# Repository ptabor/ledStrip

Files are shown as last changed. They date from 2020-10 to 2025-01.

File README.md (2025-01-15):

# ledStrip
Hobby project of (3-channel) addressable led-strips controller PCB and arduino code.

Features: 
  - power rating: 12V x 15A = 180 W combined (as designed, but depends on actual components you will use)
  - 3 channels (12V), each rated at 7A, having it's own fuse, 5V logic - tested on:
     - [WS2812B](https://www.amazon.com/stores/BTF-LIGHTING/page/0FF60378-45DE-44E7-B0D7-8F5CD6478971?ref_=ast_bln) strips.
     - [WS2815](https://www.amazon.com/stores/page/DC3DD961-F922-4197-AFD3-9C96122A1429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)
     - (but should work with any 12V power, 5V logic strips)
  - ESP32 (devkit C) powered, with Wifi support  - Web-Server control and remote firmware update 
  - [MSGEQ7](https://www.digikey.lu/htmldatasheets/production/2071107/0/0/1/MSGEQ7.pdf) spectrum analyzer connected to 3.5mm Audio Jack.
  - USB-A port (0.8A) to power the remote audio-player. 

## PCB

### Front

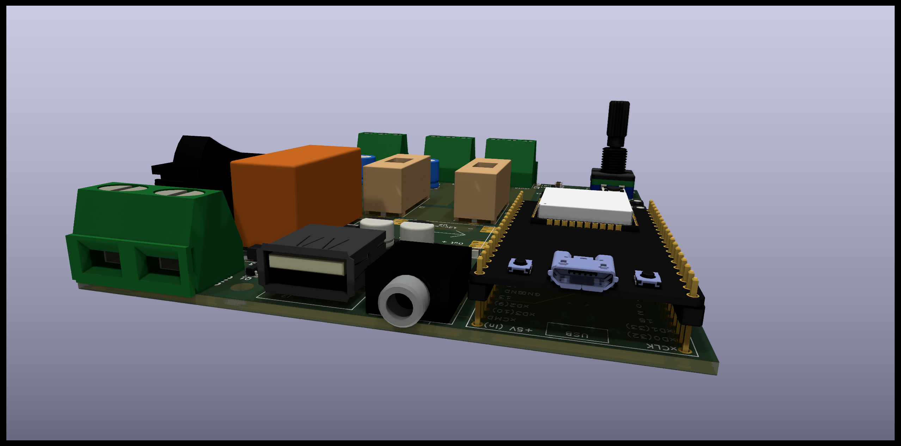
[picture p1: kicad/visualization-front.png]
Front view

  
### Back

Back view

## Building with Arduino IDE:

Install in Arduine IDE board manager:
 -ESP32
 -ESP32 from expressif 

In Arduino IDE Library manager:
 - ESP32Encoder 0.10.2
  
## WARNING

THE SOFTWARE AND HARDWARE DESIGN IS PROVIDED “AS IS”, WITHOUT WARRANTY OF ANY KIND, EXPRESS OR IMPLIED, 
INCLUDING BUT NOT LIMITED TO THE WARRANTIES OF MERCHANTABILITY, 
FITNESS FOR A PARTICULAR PURPOSE AND NONINFRINGEMENT. 
IN NO EVENT SHALL THE AUTHORS OR COPYRIGHT HOLDERS BE LIABLE FOR ANY CLAIM, 
DAMAGES OR OTHER LIABILITY, WHETHER IN AN ACTION OF CONTRACT, TORT OR OTHERWISE, 
ARISING FROM, OUT OF OR IN CONNECTION WITH THE SOFTWARE OR THE USE OR OTHER DEALINGS IN THE SOFTWARE.

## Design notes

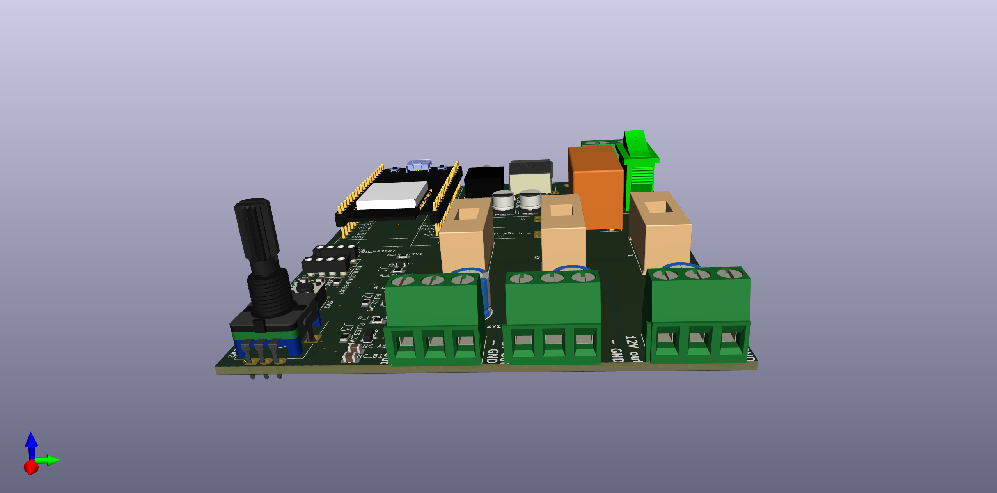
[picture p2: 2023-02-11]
kicad/visualization-back.png

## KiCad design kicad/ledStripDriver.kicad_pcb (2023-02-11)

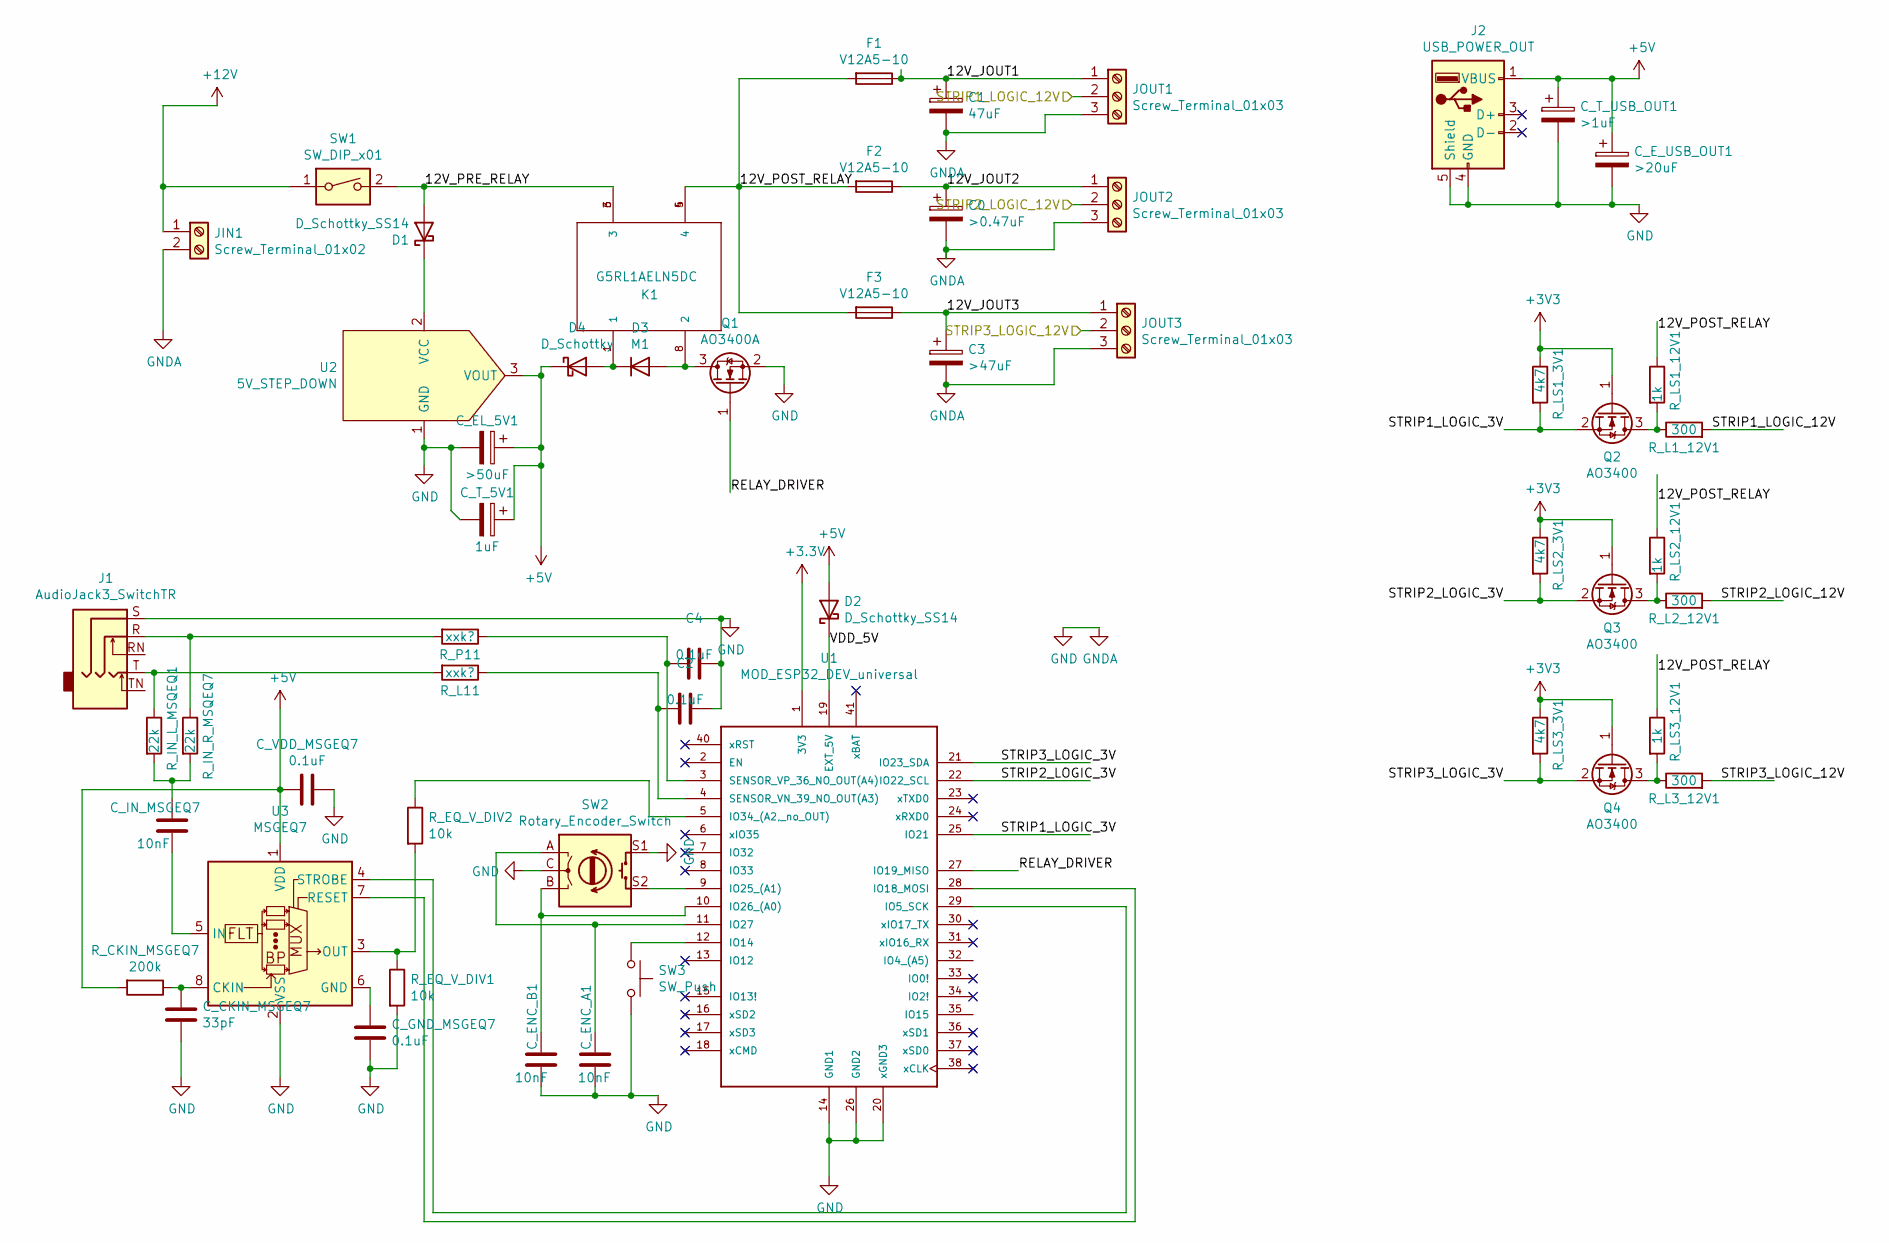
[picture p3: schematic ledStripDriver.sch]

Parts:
C0: >0.47uF; CP_Radial_D8.0mm_P3.80mm
C1: 47uF; CP_Radial_D8.0mm_P3.80mm
C2, C4: 0.1uF; C_0805_2012Metric_Pad1.15x1.40mm_HandSolder
C3: >47uF; CP_Radial_D8.0mm_P3.80mm
C_CKIN_MSGEQ7: 33pF; C_0805_2012Metric_Pad1.15x1.40mm_HandSolder
C_EL_5V1: >50uF; CP_Elec_6.3x5.4
C_ENC_A1: 10nF; C_0805_2012Metric_Pad1.15x1.40mm_HandSolder
C_ENC_B1: 10nF; C_0805_2012Metric_Pad1.15x1.40mm_HandSolder
C_E_USB_OUT1: >20uF; CP_Elec_6.3x5.4
C_GND_MSGEQ7: 0.1uF; C_0805_2012Metric_Pad1.15x1.40mm_HandSolder
C_IN_MSGEQ7: 10nF; C_0805_2012Metric_Pad1.15x1.40mm_HandSolder
C_T_5V1: 1uF; C_0805_2012Metric_Pad1.15x1.40mm_HandSolder
C_T_USB_OUT1: >1uF; C_0805_2012Metric_Pad1.15x1.40mm_HandSolder
C_VDD_MSGEQ7: 0.1uF; C_0805_2012Metric_Pad1.15x1.40mm_HandSolder
D1, D2: D_Schottky_SS14; D_SMA_Handsoldering
D3: M1; D_SMA_Handsoldering
D4: D_Schottky; D_SMA_Handsoldering
F1, F2, F3: V12A5-10; Fuseholder_Cylinder-5x20mm_Stelvio-Kontek_PTF78_Horizontal_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
J1: AudioJack3_SwitchTR; AudioJack3_SwitchTR_PJ3024
J2: USB_POWER_OUT; USB_A_CONNFLY_DS1095-WNR0
JIN1: Screw_Terminal_01x02; TerminalBlock_RND_205-00023_1x02_P10.00mm_Horizontal(2mmdri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
JOUT1, JOUT2, JOUT3: Screw_Terminal_01x03; TerminalBlock_RND_205-00002_1x03_P5.00mm_Horizontal
K1: G5RL1AELN5DC; RELAY_G5RL1AELN12DC
Q1: AO3400A; SOT-23
Q2, Q3, Q4: AO3400; SOT-23
R_CKIN_MSGEQ7: 200k; R_0805_2012Metric_Pad1.15x1.40mm_HandSolder
R_EQ_V_DIV1, R_EQ_V_DIV2: 10k; R_0805_2012Metric_Pad1.15x1.40mm_HandSolder
R_IN_L_MSQEQ1: 22k; R_0805_2012Metric_Pad1.15x1.40mm_HandSolder
R_IN_R_MSQEQ7: 22k; R_0805_2012Metric_Pad1.15x1.40mm_HandSolder
R_L1_12V1, R_L2_12V1, R_L3_12V1: 300; R_0805_2012Metric_Pad1.15x1.40mm_HandSolder
R_L11: xxk?; R_0805_2012Metric_Pad1.15x1.40mm_HandSolder
R_LS1_3V1, R_LS2_3V1, R_LS3_3V1: 4k7; R_0805_2012Metric_Pad1.15x1.40mm_HandSolder
R_LS1_12V1, R_LS2_12V1, R_LS3_12V1: 1k; R_0805_2012Metric_Pad1.15x1.40mm_HandSolder
R_P11: xxk?; R_0805_2012Metric_Pad1.15x1.40mm_HandSolder
SW1: SW_DIP_x01; ROCKER_SWITCH_7x0.5mm
SW2: Rotary_Encoder_Switch; RotaryEncoder_Alps_EC12E-Switch_Vertical_H20mm
SW3: SW_Push; SW_PUSH_6mm
U1: MOD_ESP32_DEV_universal; MOD_ESP32_DEV_DEVKITC-32D
U2: 5V_STEP_DOWN; DC_STEP_DOWN_MODULE_223_17
U3: MSGEQ7; DIP-8_W7.62mm_Socket

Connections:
+5V: C_EL_5V1.1, C_E_USB_OUT1.1, C_T_5V1.1, C_T_USB_OUT1.1, C_VDD_MSGEQ7.2, D2.2 (A), D4.1 (K), J2.1 (VBUS), R_CKIN_MSGEQ7.2, U2.3 (VOUT), U3.1 (VDD)
+12V: JIN1.1, SW1.1
/12V_JOUT1: C1.1, F1.1, JOUT1.1
/12V_JOUT2: C0.1, F2.1, JOUT2.1
/12V_JOUT3: C3.1, F3.1, JOUT3.1
/12V_POST_RELAY: F1.2, F2.2, F3.2, K1.4, K1.5 (4), R_LS1_12V1.1, R_LS2_12V1.1, R_LS3_12V1.1
/12V_PRE_RELAY: D1.2 (A), K1.3, K1.6 (3), SW1.2
/RELAY_DRIVER: Q1.1 (G), U1.27 (IO19_MISO)
/STRIP1_LOGIC_3V: Q2.2 (S), R_LS1_3V1.2, U1.25 (IO21)
/STRIP1_LOGIC_12V: JOUT1.2, R_L1_12V1.2
/STRIP2_LOGIC_3V: Q3.2 (S), R_LS2_3V1.2, U1.22 (IO22_SCL)
/STRIP2_LOGIC_12V: JOUT2.2, R_L2_12V1.2
/STRIP3_LOGIC_3V: Q4.2 (S), R_LS3_3V1.2, U1.21 (IO23_SDA)
/STRIP3_LOGIC_12V: JOUT3.2, R_L3_12V1.2
/VDD_5V: D2.1 (K), U1.19 (EXT_5V)
GND: C0.2, C1.2, C2.1, C3.2, C4.1, C_CKIN_MSGEQ7.2, C_EL_5V1.2, C_ENC_A1.2, C_ENC_B1.2, C_E_USB_OUT1.2, C_GND_MSGEQ7.2, C_T_5V1.2, C_T_USB_OUT1.2, C_VDD_MSGEQ7.1, J1.S, J2.4 (GND), J2.5 (Shield), JIN1.2, JOUT1.3, JOUT2.3, JOUT3.3, Q1.2 (S), R_EQ_V_DIV1.2, SW2.C, SW2.S1, SW3.2, U1.14 (GND1), U1.20 (xGND3), U1.26 (GND2), U2.1 (GND), U3.2 (VSS)
unnamed: C2.2, R_L11.1, U1.4 (SENSOR_VN_39_NO_OUT(A3))
unnamed: C4.2, R_P11.1, U1.3 (SENSOR_VP_36_NO_OUT(A4))
unnamed: C_CKIN_MSGEQ7.1, R_CKIN_MSGEQ7.1, U3.8 (CKIN)
unnamed: C_ENC_A1.1, SW2.A, U1.11 (IO27)
unnamed: C_ENC_B1.1, SW2.B, U1.10 (IO26_(A0))
unnamed: C_GND_MSGEQ7.1, U3.6 (GND)
unnamed: C_IN_MSGEQ7.1, R_IN_L_MSQEQ1.2, R_IN_R_MSQEQ7.2
unnamed: C_IN_MSGEQ7.2, U3.5 (IN)
unnamed: D1.1 (K), U2.2 (VCC)
unnamed: D3.1 (K), D4.2 (A), K1.1
unnamed: D3.2 (A), K1.8 (2), Q1.3 (D)
unnamed: J1.R, R_IN_R_MSQEQ7.1, R_P11.2
unnamed: J1.T, R_IN_L_MSQEQ1.1, R_L11.2
unnamed: Q2.3 (D), R_L1_12V1.1, R_LS1_12V1.2
unnamed: Q3.3 (D), R_L2_12V1.1, R_LS2_12V1.2
unnamed: Q4.3 (D), R_L3_12V1.1, R_LS3_12V1.2
unnamed: R_EQ_V_DIV1.1, R_EQ_V_DIV2.2, U3.3 (OUT)
unnamed: R_EQ_V_DIV2.1, U1.5 (IO34_(A2,_no_OUT))
unnamed: SW2.S2, U1.9 (IO25_(A1))
unnamed: SW3.1, U1.12 (IO14)
unnamed: U1.28 (IO18_MOSI), U3.7 (RESET)
unnamed: U1.29 (IO5_SCK), U3.4 (STROBE)

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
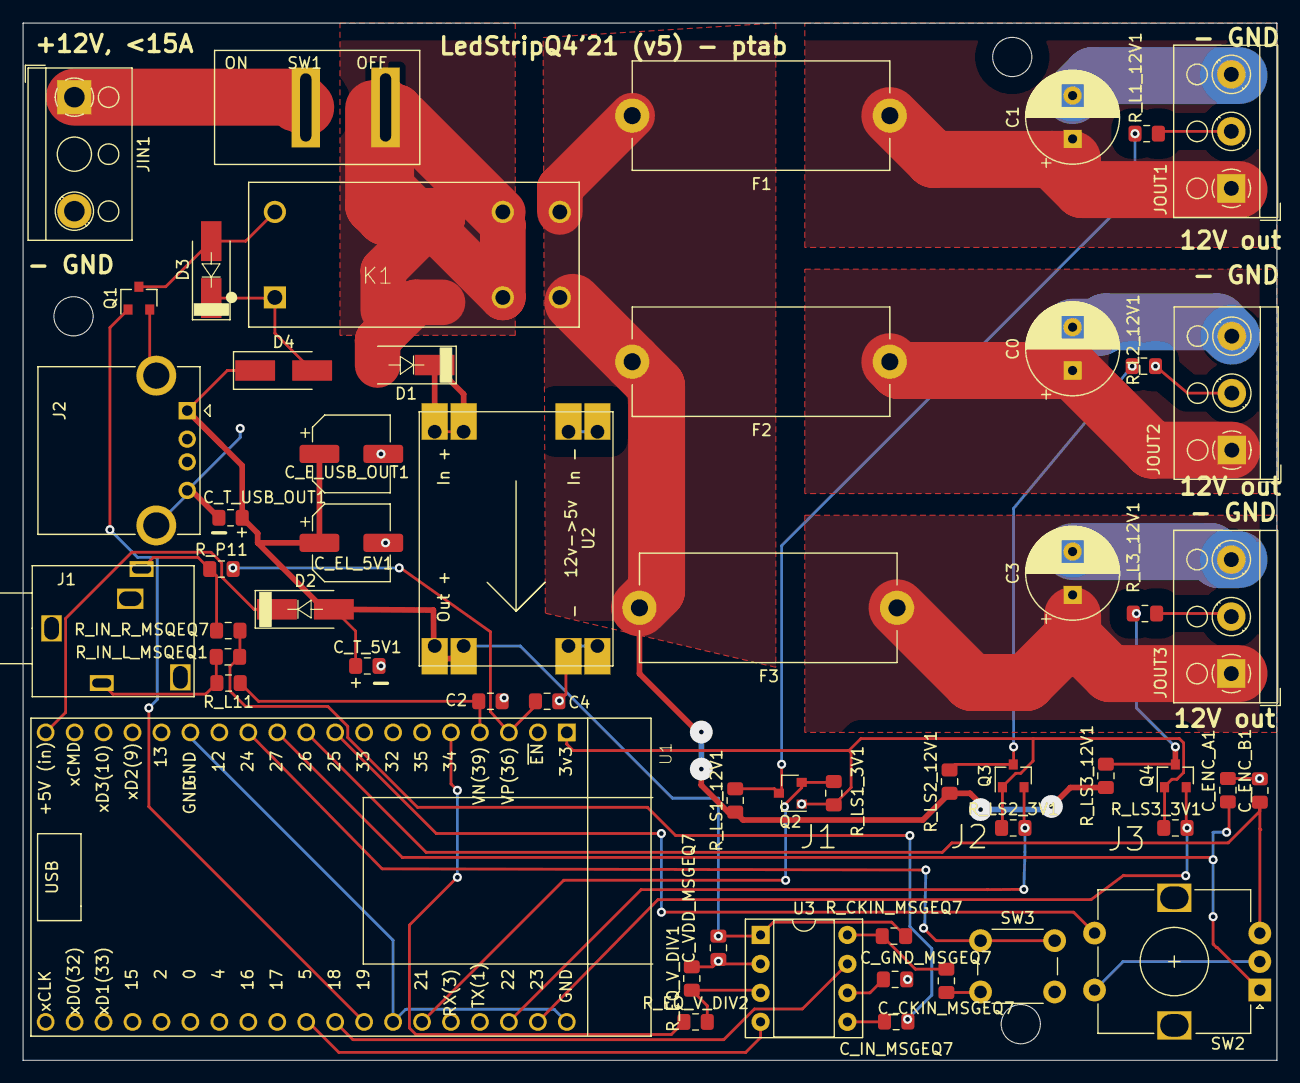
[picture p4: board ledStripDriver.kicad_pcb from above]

Board: 2 copper layers, 110.0 x 91.0 mm, 55 parts (0 on the bottom side), 39 nets.

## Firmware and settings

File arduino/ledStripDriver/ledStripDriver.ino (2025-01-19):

// Install ESP32Encoder in the LibraryManager
#include <ESP32Encoder.h>

#include <WiFi.h>
#include <WiFiClient.h>
//#include <WebServer.h>
#include <ESPmDNS.h>
#include <ArduinoOTA.h>

#include "esp_check.h"
#include "esp_http_server.h"

#include "wavelength.h"
#include "leds.h"
#include "visualizations.h"

#include "config.h"

#define PIN_BUTTON         14
#define PIN_ENCODER_BUTTON 25
#define PIN_ENCODER_A      26
#define PIN_ENCODER_B      27

#define ENCODER_MAX   25

#define PIN_RELAY 15
#define PIN_OUT1  21
#define PIN_OUT2  22
#define PIN_OUT3  23
#define NR_OF_LEDS   900

#define MSGEQ_BAND_NO 7
#define MSGEQ_STROBE_PIN    5
#define MSGEQ_RESET_PIN    18
#define MSGEQ_ANALOG_PIN  34 

// This are reads from MSGEQ7. Please notice that they are after 2x voltage devider.
#define MAX_MSGEQ_VOLTAGE 2900
// If the normalized (1-100) signal is below this value, we conisider it 0. 
#define MSGEQ_NOISE_CUTOFF 6

//========================== Wifi ===========================

//WebServer server(80);

const char* ssid     = WIFI_SSID;
const char* password = WIFI_PASSWORD;


String Index=R""""(
<html>
  <head><meta http-equiv="Content-Type" content="text/html; charset=windows-1252">    
 <title>Choinka</title>  
<script>
  function setColor() {
    var xhttp = new XMLHttpRequest();
    var col=document.getElementById('colorpicker').value.replace('#','0x');   
    xhttp.open('GET', '/color?color='+col, true);   
    xhttp.send(); }
  </script>
</head>    
<body>
  <h1>Tu choinka</h1>
  <form>
    <label for="colorpicker">Kolorek:</label>
    <input type='color' id='colorpicker' value='#0000ff' oninput='setColor()'>
    <p>power: <a href="/power?set=on">on</a> <a href="/power?set=off">off</a></p>
    <p>mode: <a href="/mode?set=0">lampki</a>
             <a href="/mode?set=1">snakes</a>
             <a href="/mode?set=2">strobo</a>
             <a href="/mode?set=3">rainbow-strobo</a>
             <a href="/mode?set=4">red</a>
             <a href="/mode?set=5">disco</a>
             <a href="/mode?set=6">rainbow</a>
             <a href="/mode?set=7">pulse</a> 
             <a href="/mode?set=8">snow</a>      
             <a href="/mode?set=9">snow-color</a>         
             <a href="/mode?set=10">google</a>
             <a href="/mode?set=11">ukraina</a>  
             <a href="/mode?set=12">snow</a>   
    </p>
    </form>
</body>
</html>)"""";


bool setupWifi() { 
  WiFi.mode(WIFI_STA);
  WiFi.begin(ssid, password);
  Serial.println("Wifi begin called...");

    // Wait for connection
  for (int i=0; (i< 100)&&(WiFi.status() != WL_CONNECTED); ++i) {
    delay(500);
    Serial.print(".");
    Serial.println(WiFi.status());
  }
  if (WiFi.status() != WL_CONNECTED) {
    Serial.print("Wifi connection FAILED !!!");
    return false;
  }
  Serial.print("Wifi connected");
  Serial.println("");
  Serial.print("Connected to ");
  Serial.println(ssid);
  Serial.print("IP address: ");
  Serial.println(WiFi.localIP());

  Serial.println("HTTP server started");
  return true;
}

void setupOTA() {
  ArduinoOTA.setHostname("choinka");
  ArduinoOTA.setPort(3232);
  ArduinoOTA
    .onStart([]() {
      String type;
      if (ArduinoOTA.getCommand() == U_FLASH)
        type = "sketch";
      else // U_SPIFFS
        type = "filesystem";

      // NOTE: if updating SPIFFS this would be the place to unmount SPIFFS using SPIFFS.end()
      Serial.println("Start updating " + type);
    })
    .onEnd([]() {
      Serial.println("\nEnd");
    })
    .onProgress([](unsigned int progress, unsigned int total) {
      Serial.printf("Progress: %u%%\r", (progress / (total / 100)));
    })
    .onError([](ota_error_t error) {
      Serial.printf("Error[%u]: ", error);
      if (error == OTA_AUTH_ERROR) Serial.println("Auth Failed");
      else if (error == OTA_BEGIN_ERROR) Serial.println("Begin Failed");
      else if (error == OTA_CONNECT_ERROR) Serial.println("Connect Failed");
      else if (error == OTA_RECEIVE_ERROR) Serial.println("Receive Failed");
      else if (error == OTA_END_ERROR) Serial.println("End Failed");
    });

  ArduinoOTA.begin();
}

// =========================  MSGEQ7       =================== 

// We normalize band-values such that they contain values from 0-100. 
// We consider values <5 as noise and normalize to 0.
int bandValues[MSGEQ_BAND_NO];
 
void setupMSGEQ7()
{
  pinMode(MSGEQ_RESET_PIN, OUTPUT);
  pinMode(MSGEQ_STROBE_PIN, OUTPUT);
 
  // RESET
  digitalWrite(MSGEQ_RESET_PIN, LOW);
  digitalWrite(MSGEQ_STROBE_PIN, HIGH);
}

void printBands() {
  for (int bandNo = 0; bandNo < MSGEQ_BAND_NO; bandNo++) {
    Serial.printf("%4d ", bandValues[bandNo]);
  }
  Serial.println();
}

// This implementation takes ~210usec due to delay between bands.
void readMSGEQ7()
{
  digitalWrite(MSGEQ_RESET_PIN, HIGH);
  digitalWrite(MSGEQ_RESET_PIN, LOW);
 
  for (int bandNo = 0; bandNo < MSGEQ_BAND_NO; bandNo++)
  {
    digitalWrite(MSGEQ_STROBE_PIN, LOW);
    delayMicroseconds(30);
    bandValues[bandNo] = (analogRead(MSGEQ_ANALOG_PIN) * 100) / 2800;
    if (bandValues[bandNo] <= MSGEQ_NOISE_CUTOFF) {
      bandValues[bandNo]=0;
    }
    digitalWrite(MSGEQ_STROBE_PIN, HIGH);
  }
  printBands();
}


// ==============================================================

struct led_channel_t *leds1 = NULL;
struct led_channel_t *leds2 = NULL;
struct led_channel_t *leds3 = NULL; 

ESP32Encoder encoder;

void setupButtons() {
  pinMode(PIN_BUTTON, INPUT_PULLUP);
}

void setupEncoder() {
  ESP32Encoder::useInternalWeakPullResistors=puType::up;
  encoder.attachSingleEdge(PIN_ENCODER_A, PIN_ENCODER_B);
  encoder.setCount(ENCODER_MAX);

  pinMode(PIN_ENCODER_BUTTON, INPUT_PULLUP);
}

void setup() 
{
    Serial.begin(115200);

    pinMode(PIN_RELAY, OUTPUT);

    delay(1000);
    digitalWrite(PIN_RELAY, HIGH);   // turn the power to the strip

    leds1 = setupLedChannel(PIN_OUT1, NR_OF_LEDS);
    if (!leds1) {
      Serial.printf("Cannot initialize stipe1");
    }
    
    // leds2 = setupLedChannel(PIN_OUT2, 1);
    // if (!leds2) {
    //   Serial.printf("Cannot initialize stipe1");
    // }
    
    // leds3 = setupLedChannel(PIN_OUT3, 1);
    // if (!leds3) {
    //   Serial.printf("Cannot initialize stipe1");
    // }

    setupMSGEQ7();
    
    ledTestSequence();

    setupButtons();
    setupEncoder();

    setupWifi();
    setupOTA();

    MDNS.addService("http", "tcp", 80);
    Serial.println("MDNS responder started");
    
    start_webserver();

    Serial.printf("\n\nInit DONE");
}

void ledTestSequence() {

  uint32_t kolory[] = { 0xFF4500, /*0xFFD7000xDAA520,*/ 0xFF4500, /*0x32CD32*/ 0x006400, 0x808000, /*0x4682B4*/0x191970, 0x8B4513, 0x800000};
  for (int i=0; i<7; ++i) {
    drawColor(leds1, kolory[i]);
    delay(1000);
  }

  // for(int i=0; i < leds1->length; ++i) {
  //    prefix(leds1, i, RGB_RED);    
  //    delay(1);
  // }
  drawColor(leds1, RGB_RED);
  drawColor(leds2, RGB_RED);
  drawColor(leds3, RGB_RED);
  delay(500);
  drawColor(leds1, RGB_GREEN);
  drawColor(leds2, RGB_GREEN);
  drawColor(leds3, RGB_GREEN);
  delay(500);
  drawColor(leds1, RGB_BLUE);
  drawColor(leds2, RGB_GREEN);
  drawColor(leds3, RGB_RED);
  delay(500);
  drawColor(leds1, RGB_WHITE);
  drawColor(leds2, RGB_WHITE);
  drawColor(leds3, RGB_WHITE);
  delay(500);
  drawColor(leds1, RGB_BLACK);
  drawColor(leds2, RGB_BLACK);
  drawColor(leds3, RGB_BLACK);
}

bool checkButton1pressed() {
  static bool buttonPrev = false;
  boolean buttonPressed = digitalRead(PIN_BUTTON) == 0;
  if (!buttonPrev && buttonPressed) {
    buttonPrev = true;
    return true;
  }
  buttonPrev = buttonPressed;
  return false;
}

bool checkButtonEncPressed() {
  static bool buttonPrev = false;
  boolean buttonPressed = digitalRead(PIN_ENCODER_BUTTON) == 0;
  if (!buttonPrev && buttonPressed) {
    buttonPrev = true;
    return true;
  }
  buttonPrev = buttonPressed;
  return false;
}

bool on = true;
int mode = 0;
int prev_ms;
float brightness = 1.0;
int color = RGB_RED;

void readBrighnessFromEncoder() {
  if (brightness <= 0.0) {
    if (checkButtonEncPressed()) {
      encoder.setCount(ENCODER_MAX);
    }
    if (encoder.getCount() > ENCODER_MAX) {
      encoder.setCount(ENCODER_MAX);
    }
    if (encoder.getCount() < 0) {
      encoder.setCount(0);
    }
    // Exponential brightness works better. 1.22^25 ~=100.
    leds1->brightness = encoder.getCount() == 0 ? 0.0 : min(pow(1.22, encoder.getCount()-1), 100.0) / 100.0; 
  //  Serial.println("Encoder count = " + String((int32_t)encoder.getCount()) + " brighness:" + leds1->brightness);
  } else {
    leds1->brightness = brightness;
  }
}

//=========================

esp_err_t index_handler(httpd_req_t *req)
{
    /* Send a simple response */
    //const char resp[] = Index.c_str();
    httpd_resp_send(req, Index.c_str(), HTTPD_RESP_USE_STRLEN);
    return ESP_OK;
}

httpd_uri_t uri_index = {
    .uri      = "/",
    .method   = HTTP_GET,
    .handler  = index_handler,
    .user_ctx = NULL
};

esp_err_t handleBrightness(httpd_req_t *req) {
  int b = getParamInt(req, "b");
  brightness = max(min(1.0, b/100.0), 0.0);

  httpd_resp_send(req, "OK", HTTPD_RESP_USE_STRLEN);
  Serial.print("handleBrightness DONE\n");
  return ESP_OK;
}

esp_err_t handleMode(httpd_req_t *req) {
  int m = getParamInt(req, "set");
  mode = m;

  httpd_resp_send(req, "OK", HTTPD_RESP_USE_STRLEN);
  Serial.print("handleMode DONE:" + String(mode) + "\n");
  return ESP_OK;
}

esp_err_t handleColor(httpd_req_t *req) {
  color = getParamInt(req, "color");
  mode = 4;

  httpd_resp_send(req, "OK", HTTPD_RESP_USE_STRLEN);
  Serial.print("handleColor DONE\n");
  return ESP_OK;
}

esp_err_t handlePower(httpd_req_t *req) {
  char out[10];
  getParam(req, "set", out, sizeof(out));
  String s(out);
  // brightness = max(min(1.0, b/100.0), 0.0);

  if(s=="on") {
    digitalWrite(PIN_RELAY, HIGH); 
    on = true;
  }
  if(s=="off") {
    digitalWrite(PIN_RELAY, LOW); 
    on = false;
  }

  httpd_resp_send(req, "OK", HTTPD_RESP_USE_STRLEN);
  Serial.print("handlePower DONE\n");
  return ESP_OK;
}

esp_err_t handleStatus(httpd_req_t *req) {
  Serial.printf("handleStatus\n");
  String message = "{\n";
  message += "  \"power\": " + String(on?"true":"false") + String(",\n");
  message += "  \"brightness\": " + String((int)(brightness*100)) + ",\n";
  message += "  \"mode\": " + String(mode) + ",\n";
  message += "  \"color\": " + String(color) + "\n";
  message += "}\n";

  httpd_resp_send(req, message.c_str(), message.length());
  return ESP_OK;
}

httpd_uri_t uri_brightness = {.uri      = "/brightness", .method   = HTTP_GET,  .handler  = handleBrightness, .user_ctx = NULL};
httpd_uri_t uri_power = {.uri           = "/power", .method   = HTTP_GET,  .handler  = handlePower, .user_ctx = NULL};
httpd_uri_t uri_mode  = {.uri           = "/mode",       .method   = HTTP_GET,  .handler  = handleMode, .user_ctx = NULL};
httpd_uri_t uri_color = {.uri           = "/color",      .method   = HTTP_GET,  .handler  = handleColor, .user_ctx = NULL};
httpd_uri_t uri_status = {.uri           = "/status",      .method   = HTTP_GET,  .handler  = handleStatus, .user_ctx = NULL};


httpd_handle_t start_webserver(void)
{
    /* Generate default configuration */
    httpd_config_t config = HTTPD_DEFAULT_CONFIG();

    /* Empty handle to esp_http_server */
    httpd_handle_t server = NULL;

    /* Start the httpd server */
    if (httpd_start(&server, &config) == ESP_OK) {
        /* Register URI handlers */
        httpd_register_uri_handler(server, &uri_index);
        httpd_register_uri_handler(server, &uri_brightness);
        httpd_register_uri_handler(server, &uri_power);
        httpd_register_uri_handler(server, &uri_mode);
        httpd_register_uri_handler(server, &uri_color);
        httpd_register_uri_handler(server, &uri_status);
    }
    /* If server failed to start, handle will be NULL */
    return server;
}

// void handleColor() {
//   Serial.print("handleColor\n");
//   String c=server.arg(0);
//   color = std::stoul(c.c_str(),nullptr, 0);
//   setMode(4); 
//   server.send(200, "text/plain", "OK");
// }

static const char* WEBSERVER_TAG = "PilotWebserver";

esp_err_t getParam(httpd_req_t *req, char* paramName, char* param, int sizeOfParam) {
  int buf_len = httpd_req_get_url_query_len(req) + 1;
  if (buf_len > 1) {
        char* buf = (char*)malloc(buf_len);
        ESP_RETURN_ON_FALSE(buf, ESP_ERR_NO_MEM, WEBSERVER_TAG, "buffer alloc failed");
        if (httpd_req_get_url_query_str(req, buf, buf_len) == ESP_OK) {
            ESP_LOGI(WEBSERVER_TAG, "Found URL query => %s", buf);
            /* Get value of expected key from query string */
            if (httpd_query_key_value(buf, paramName, param, sizeOfParam) == ESP_OK) {
                ESP_LOGI(WEBSERVER_TAG, "Found URL query parameter => query1=%s", param);
                return ESP_OK;
                // example_uri_decode(dec_param, param, strnlen(param, EXAMPLE_HTTP_QUERY_KEY_MAX_LEN));
                // ESP_LOGI(TAG, "Decoded query parameter => %s", dec_param);
            }
        }
  }
  return ESP_ERR_INVALID_ARG;
}

int getParamInt(httpd_req_t *req, char* paramName) {
  char param[10];
  getParam(req, paramName, param, sizeof(param));
  return std::stoul(param,nullptr, 0);
}

//=========================

void setMode(int new_mode) {
  if (new_mode != mode) {
  //  drawColor(leds1, 0x000000);
    mode = new_mode;
    prev_ms=0;    
  }
}

void loop() {
  //server.handleClient();
  ArduinoOTA.handle();
// //  for (int i=0; i<3000; ++i) {
     readBrighnessFromEncoder();
    
    if (checkButton1pressed()) {
      setMode((mode+1)%13);
      Serial.printf("Button1 pressed. Mode: %d\n", mode);
    }
  
    int time_ms = millis();    

   switch (mode) {
     case 0: 
       lampki(leds1, time_ms, prev_ms);
       //delay(1);
       break;
     case 1: 
       rainbowSnakesDemo(leds1, time_ms);
       //delay(10);
       break;
     case 2: 
       readMSGEQ7();
       stroboSimple(leds1, bandValues);  
       //delay(10);
       break;
     case 3: 
       readMSGEQ7();
       rainbowSnakesStrobo(leds1, time_ms, bandValues);
       //delay(10);
       break;
     case 4: 
       drawColor(leds1, color);
       //delay(100);
       break;
    //  case 6:
    //    oneByOne(leds1, time_ms, 1000);
    //    delay(100);
    //    break;
    //  case 8:
    //    blyskawica(leds1, time_ms);
    //    delay(10);
    //    break;
    //  case 7: 
    //    choinka(leds1, time_ms);
    //    delay(10);
    //    break;
     case 5: 
       grzesia(leds1, time_ms);
      //  drawColor(leds1, RGB_BLACK);
      //  drawColor(leds2, RGB_BLACK);
      //  drawColor(leds3, RGB_BLACK); 
       //delay(1);
       break;
     case 6: 
       rainbow(leds1, time_ms);
      //  drawColor(leds1, RGB_BLACK);
      //  drawColor(leds2, RGB_BLACK);
      //  drawColor(leds3, RGB_BLACK); 
       break;

    case 7:
      pulses(leds1, time_ms, 0x00ff00);
      //delay(1);
    //  case 10:
    //    choinkaBlyskawica(leds1, time_ms);
    //    delay(10);
      break;
     case 8:
      snow(leds1, time_ms, /*0xffffff*/ 0xfaebd7);
      //delay(1);
      break;
    case 9: {
      uint32_t kolory[] = { 0xFF4500, /*0xFFD7000xDAA520,*/ 0xFF4500, /*0x32CD32*/ 0x006400, 0x808000, /*0x4682B4*/0x191970, 0x8B4513, 0x800000};
      snow(leds1, time_ms, kolory, 7);
      //delay(1);
      break;
    }
    case 10: {
    //  uint32_t google[] = { 0x4285F4,0xDB4437, 0xF4B400, 0x4285F4, 0x0F9D58, 0xDB4437};
      uint32_t G_BLUE=0x4285F4;
      uint32_t G_GREEN=0x34A853;
      uint32_t G_YELLOW=0xFBBC05;
      uint32_t G_RED=0xEA4335;
      //BLUE,

    //  uint32_t google[] = { G_RED,G_GREEN,G_BLUE, G_YELLOW,G_RED,G_BLUE};
      uint32_t google[] = { G_BLUE, G_RED, G_YELLOW, G_BLUE, G_GREEN, G_RED};
     // brightness = 0.1;
      strips(leds1, 0, 500, google, 6);
      break;
    }
    case 11: {
      uint32_t ukraina[] = { 0x0057b7,0xffd700};
     // brightness = 0.3;
      strips(leds1, time_ms, 100000000.0, ukraina, 2);
      break;
    }
    case 12: {
      snowIncremental(leds1, time_ms);
      break;
    }   
   }
    prev_ms = time_ms;
//    Serial.printf("%d %d %d %d\n", digitalRead(PIN_BUTTON), digitalRead(PIN_ENCODER_BUTTON), digitalRead(PIN_ENCODER_A), digitalRead(PIN_ENCODER_B));
//  }
//  Serial.printf("Next", mode);
//  mode++;
//  prev_ms=0;
}

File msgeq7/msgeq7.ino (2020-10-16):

int MSGEQ_STROBE_PIN = 5;
int MSGEQ_RESET_PIN = 18;
int MSGEQ_ANALOG_PIN = 4;

int bandValues[7];
int bandNo;
 
//char buf[4];
 
void setup()
{
  Serial.begin(115200)

 
  pinMode(MSGEQ_RESET_PIN, OUTPUT);
  pinMode(MSGEQ_STROBE_PIN, OUTPUT);
 
  // RESET
  digitalWrite(MSGEQ_RESET_PIN, LOW);
  digitalWrite(MSGEQ_STROBE_PIN, HIGH);
}
 
void readMSGEQ7()
{
  digitalWrite(MSGEQ_RESET_PIN, HIGH);
  digitalWrite(MSGEQ_RESET_PIN, LOW);
 
  for (bandNo = 0; bandNo < 7; bandNo++)
  {
    digitalWrite(MSGEQ_STROBE_PIN, LOW);
    delayMicroseconds(30);
    bandValues[bandNo] = analogRead(ANALOG_PIN);
    digitalWrite(MSGEQ_STROBE_PIN, HIGH);
  }
}
 
void loop()
{
  // pobieramy amplitudy
  readMSGEQ7();
 
  // wyswietlamy kolejne zakresy
  for (bandNo = 0; bandNo < 7; bandNo++)
  {
   // sprintf(buf, "aa");
    
   // Serial.print(buf);
    Serial.printf("%4d ", bandValues[bandNo]);
  }
  Serial.println();
}

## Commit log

2020-02-21 Before PCB Manufacturing Q1'2020
    [ledStripDriver-B_Cu.gbr, ledStripDriver-B_Mask.gbr, ledStripDriver-B_Paste.gbr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]
2020-03-03 Confirmed to work version of arduino software (1-strip on WS2815 showing rainbow). Running on PCB Q1-2020.
2020-03-22 KiCad fixes: flip Jack, add resistor on 12V logic to protect LEDs.
    [ledStripDriver.kicad_pcb, ledStripDriver.sch]
2020-08-23 Modified schema to consiste MSQ spectrum analyzer. No PCB updates yet.
    [ledStripDriver.sch]
2020-08-23 Refreshed PCB and footprints of (Fuse holder, Rocker switch, Screw-terminal for input)
    [ledStripDriver.kicad_pcb, ledStripDriver.sch]
2020-08-26 PCB v2 - with hardware spectrum analyzer.
    [ledStripDriver.kicad_pcb, ledStripDriver.sch]
2020-10-04 Revision 2 - Q3'2020 -> Printed board (rev2), Software confirmed to work. No support for Jack yet.
    [ledStripDriver-B_Cu.gbr, ledStripDriver-B_Mask.gbr, ledStripDriver-B_Paste.gbr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]
2020-10-05 Blink to Music on MSGEQ07 - prototype
2020-10-10 PCB v3: Hopefully manufacturing ready.
    [ledStripDriver-B_Cu.gbr, ledStripDriver-B_Mask.gbr, ledStripDriver-B_Paste.gbr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]
2020-10-16 With charging port.
    [ledStripDriver-B_Cu.gbr, ledStripDriver-B_Mask.gbr, ledStripDriver-B_Paste.gbr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]
2020-12-06 v3 - working and split between files. StroboRainbows.
    [ledStripDriver.kicad_pcb, ledStripDriver.sch]
2020-12-06 Encoder programmed.
2021-03-13 v4 - preprod
    [ledStripDriver-B_Cu.gbr, ledStripDriver-B_Mask.gbr, ledStripDriver-B_Paste.gbr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]
2021-12-12 V4-board. Christmat 2021 - before implementing Wifi support.
2022-01-16 Rainbow is pulsing. MDNS correctly configured. drawMap(...) is not injecting any delay.
    [ledStripDriver.kicad_pcb, ledStripDriver.sch]
2023-02-11 Link components to 3d images. Render back and front.
    [ledStripDriver.kicad_pcb]
2025-01-15 Updated to Arduino/ESP32 3.0 version (mostly RMT interface).
2025-02-03 First version of home assistant support in ledStrip.
